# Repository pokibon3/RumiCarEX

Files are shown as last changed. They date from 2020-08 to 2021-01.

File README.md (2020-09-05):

# RumiCarEX
## Original RumiCar Project

### rumicar_esp32

- CPU        : ESP32 mini
- Chassis    : Original
- Steering   : Servo Motor 
- TOF Senser : VL53L1X
- Program    : Original

### rumicar_LiDAR(sense only)

- CPU        : M5Atom Matrix
- Chassis    : Original
- Steering   : Servo Motor 
- TOF Senser : LiDAR Camsense X1
- Program    : Original

### rumicar_atom

- CPU        : M5Atom Matrix
- Chassis    : Original
- Steering   : Servo Motor 
- TOF Senser : VL53L1X
- Program    : Original

### rumicar_xiao

 - CPU       : seeed xiao
 - Chassis   : DAISO 600 Yen Toy Radio Control Car
 - TOF Sensor: VL53L0X
 - Program   : RumiCar EX3.1

 ### libraries/LV53L1X

  - Add VL53L1X_SetROI function

### 1.Test
 
  - Test Programs

### 2.doc

  - related documents

### 3.Log

  - Driving Log

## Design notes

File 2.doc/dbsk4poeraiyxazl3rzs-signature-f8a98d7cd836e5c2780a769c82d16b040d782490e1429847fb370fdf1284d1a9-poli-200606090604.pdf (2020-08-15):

# RumiCarのモータ制御と今後の展開

### For 実機貸出有！【オンライン】RumiCarハンズオン！ 自動運転アルゴリズムを楽しく手軽に体感しよう！

ミイシステム株式会社） 稲玉 繁樹
Rev.)2020/06/06

いなたま しげき

ALL Pages Photo OK! | 四の人(IoT) @InatamaS

Mii system Co.,Ltd.

### RumiCar ライブラリによって，走らせる事は簡単になっていますが， - モータ制御って何？どうなってるの？ - 今後，どんな進化するの？ について説明します。

### 伝えたいこと

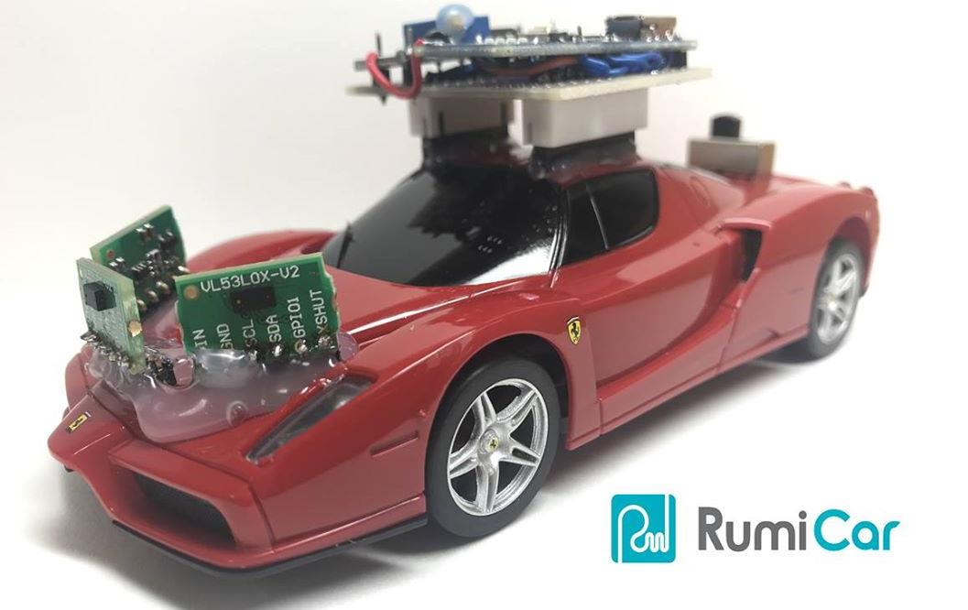
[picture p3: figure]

### - モータを動かすことは，とても楽しいです - 電気を扱うため，安全に注意してください - モータ制御は難しいけど理解するほど楽しいことができます，がんばろう - 正しい知識を持って，電子工作をもっと楽しもう

## Today’s contents

## Who

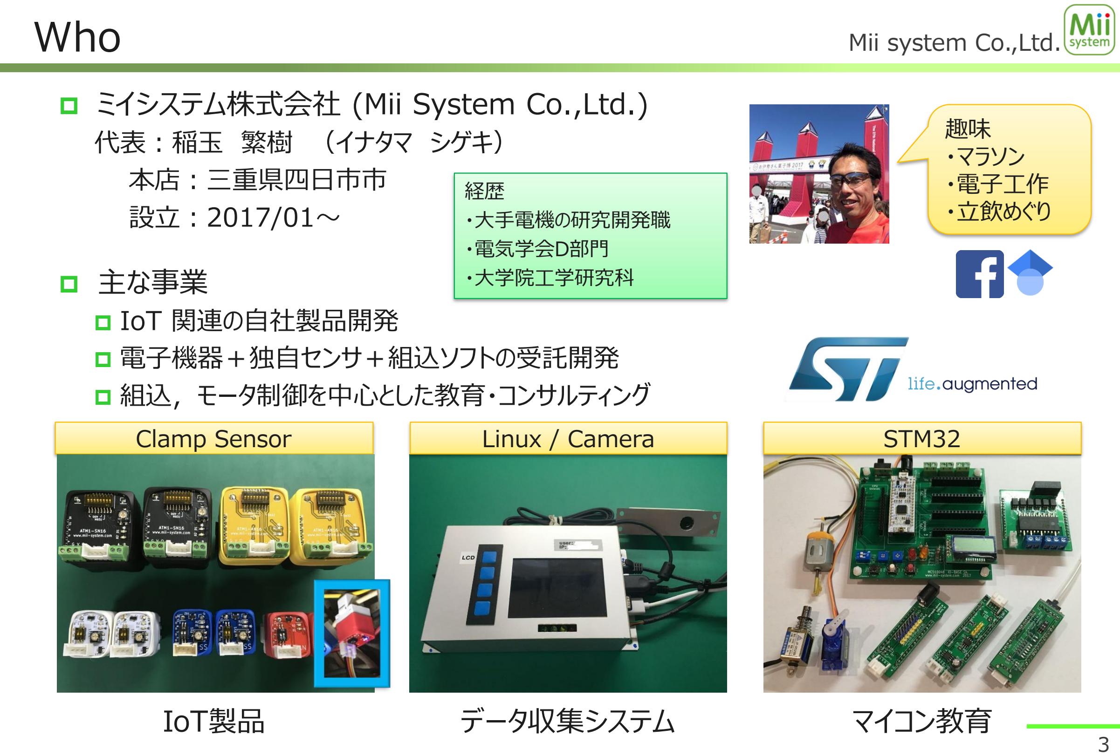
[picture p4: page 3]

Mii system Co.,Ltd.

マイコン教育

- ミイシステム株式会社 (Mii System Co.,Ltd.) 代表：稲玉 繁樹 （イナタマ シゲキ）
本店：三重県四日市市
設立：2017/01～
IoT製品 | データ収集システム
Clamp Sensor | Linux / Camera | STM32

趣味
・マラソン
・電子工作
・立飲めぐり
- 主な事業
- IoT 関連の自社製品開発
- 電子機器＋独自センサ＋組込ソフトの受託開発
- 組込，モータ制御を中心とした教育・コンサルティング

経歴
・大手電機の研究開発職
・電気学会D部門
・大学院工学研究科

## モータの種類

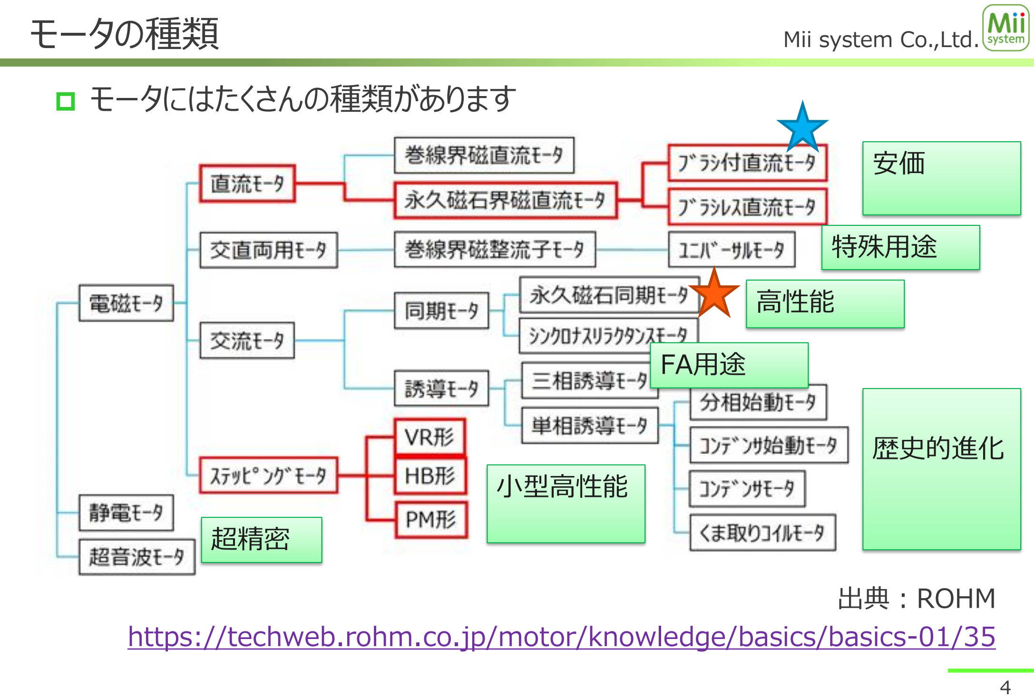
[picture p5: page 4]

Mii system Co.,Ltd.

### - モータにはたくさんの種類があります

出典：ROHM
https://techweb.rohm.co.jp/motor/knowledge/basics/basics-01/35

安価

小型高性能

超精密

特殊用途

高性能

FA用途

歴史的進化

Mii system Co.,Ltd.

### - DCモータ，about な理解 - 電池を入れると同じ方向に回り続ける - 電池の向きで回転する方向が変わる - 電池の本数で回転するスピードが変わる

### - DCモータが回転する仕組み

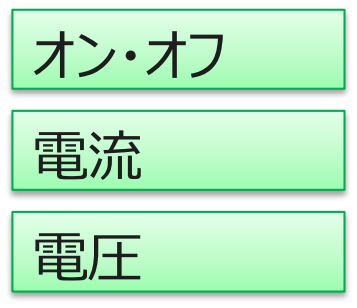
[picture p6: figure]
電流 電圧電圧

### マブチモーター株式会社-モーターのしくみを知ろう

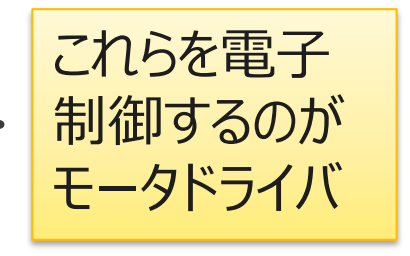
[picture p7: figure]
これらを電子 制御するのが モータドライバ

https://www.mabuchi-motor.co.jp/motorize/academy/mechanism/

## モータはなぜ回るのか

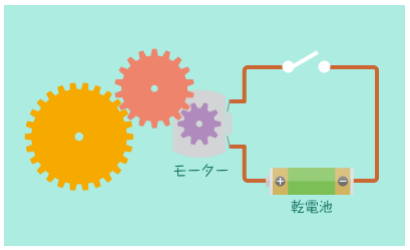
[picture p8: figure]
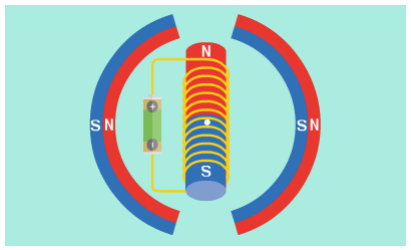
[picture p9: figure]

## モータ制御って何？

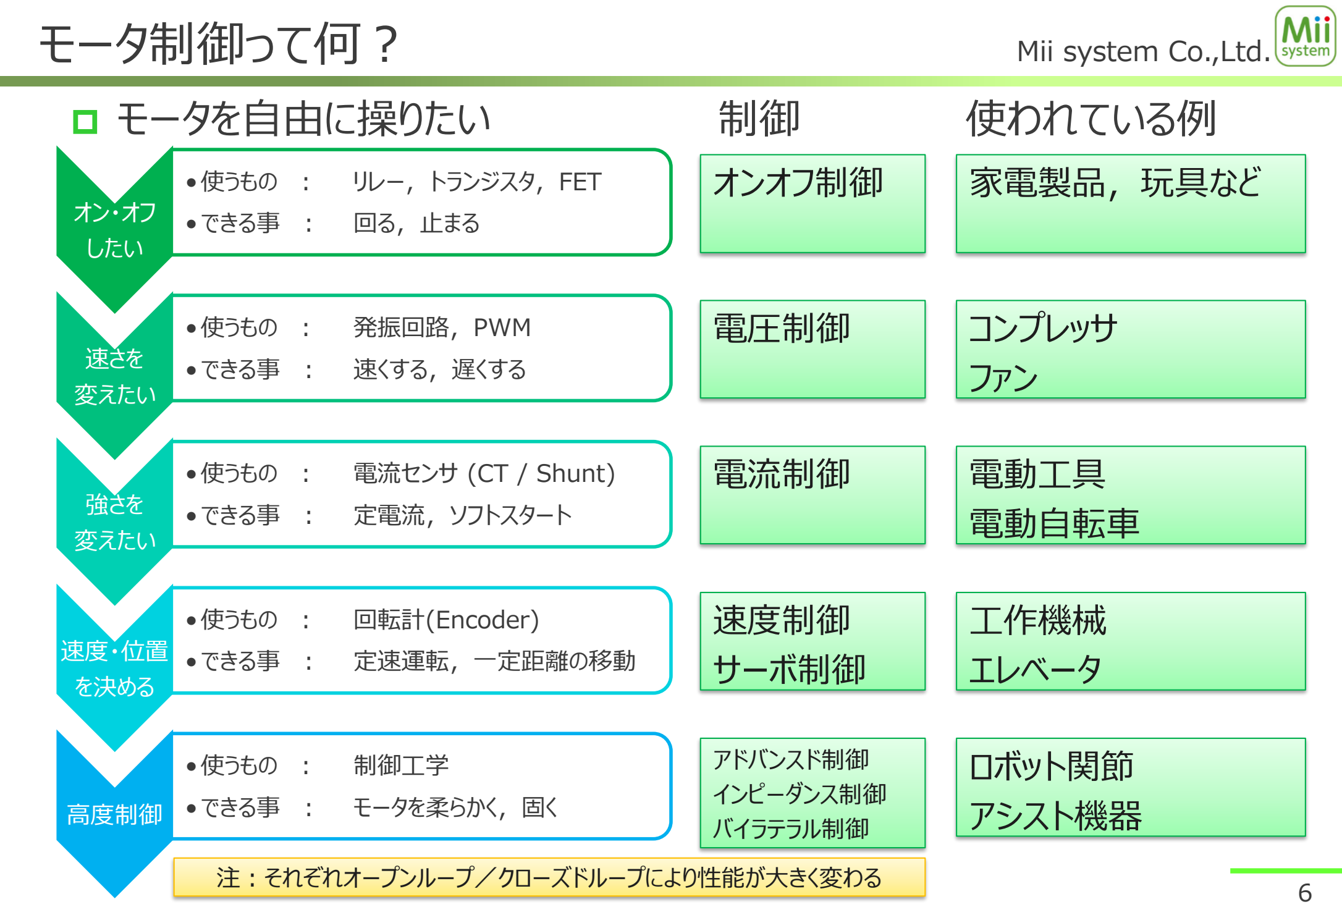
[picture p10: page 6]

Mii system Co.,Ltd.
- モータを自由に操りたい | 制御 | 使われている例

オン・オフ
したい
•使うもの ： | リレー，トランジスタ，FET
•できる事 ： | 回る，止まる

速さを
変えたい
•使うもの ： | 発振回路，PWM
•できる事 ： | 速くする，遅くする

強さを
変えたい
•使うもの ： | 電流センサ (CT / Shunt)
•できる事 ： | 定電流，ソフトスタート

速度・位置
を決める
•使うもの ： | 回転計(Encoder)
•できる事 ： | 定速運転，一定距離の移動

高度制御

•使うもの ： | 制御工学
•できる事 ： | モータを柔らかく，固く

家電製品，玩具など

コンプレッサ
ファン

電動工具
電動自転車

工作機械
エレベータ

ロボット関節
アシスト機器

オンオフ制御

電圧制御

電流制御

速度制御
サーボ制御

アドバンスド制御
インピーダンス制御
バイラテラル制御

注：それぞれオープンループ／クローズドループにより性能が大きく変わる

Mii system Co.,Ltd.

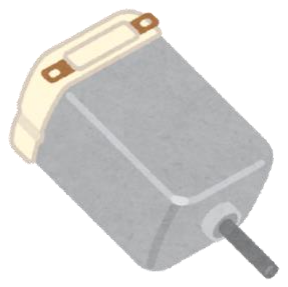
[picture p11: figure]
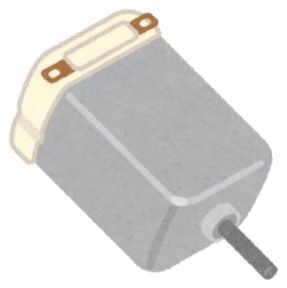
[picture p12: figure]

### - 走る・曲がる・止まる の性能アップ

- 一定速度で走る，なめらかな加減速
- ステアリング用エンコーダで切れ角を制御

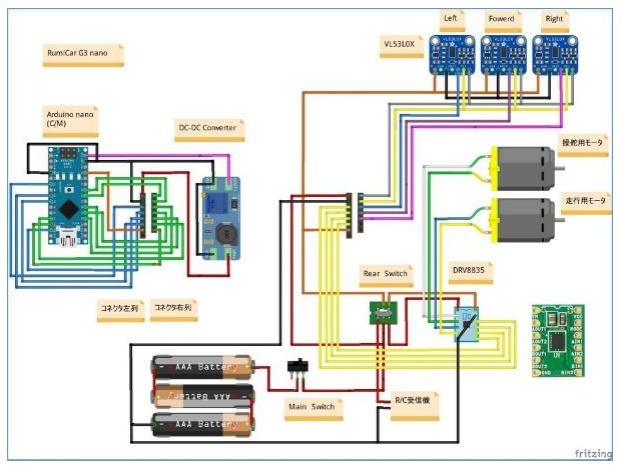
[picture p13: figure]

### - ユニット化で組み立てやすく

- センサ基板 / CPU基板 / MD基板を標準化
- はんだ付けを減らし，組立しやすく

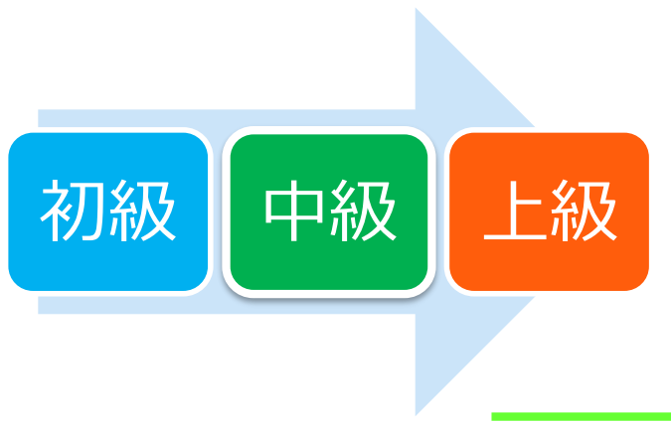
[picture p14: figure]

### - ソフトを作りやすく / 高度化へ

- Node-red / UIFlow などのブロック言語を活用
- ESP32 のWi-Fi (OTA) 書き込み
- Wi-FiでMD/センサ情報をやりとりし，PC側で制御する

## RumiCar 新バージョンの構想

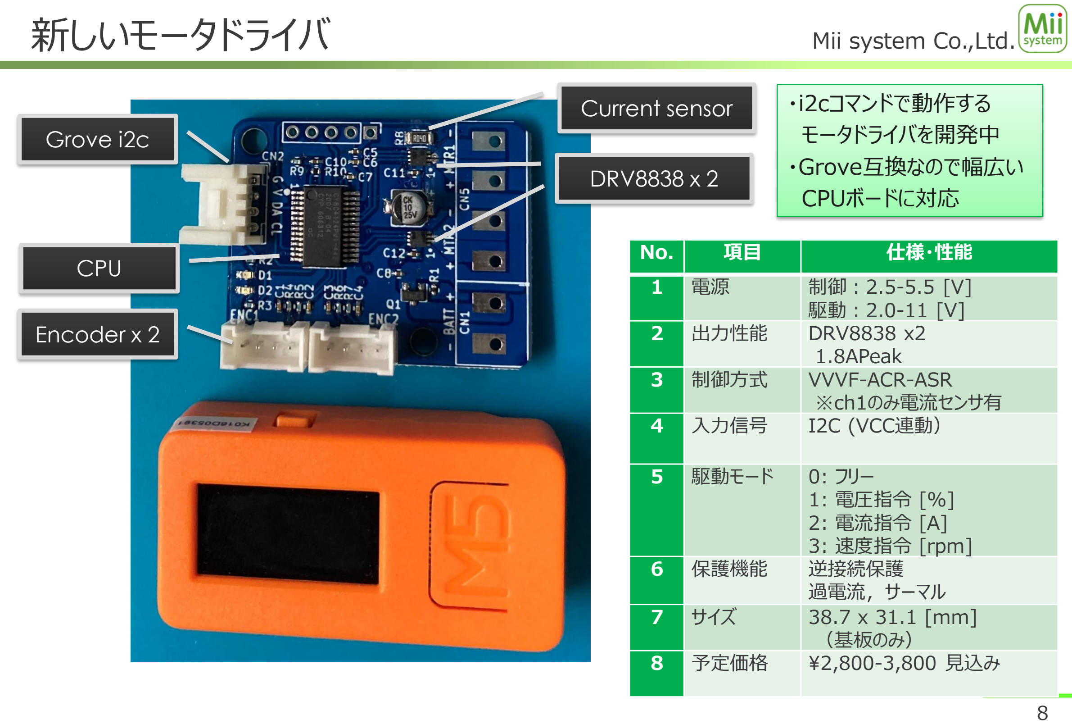
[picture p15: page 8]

新しいモータドライバ | Mii system Co.,Ltd.

Grove i2c

Encoder x 2

Current sensor

DRV8838 x 2

CPU

No. | 項目 | 仕様・性能
1 | 電源 | 制御：2.5-5.5 [V] 駆動：2.0-11 [V]
2 | 出力性能 | DRV8838 x2 1.8APeak
3 | 制御方式 | VVVF-ACR-ASR ※ch1のみ電流センサ有
4 | 入力信号 | I2C (VCC連動）
5 | 駆動モード | 0: フリー 1: 電圧指令 [%] 2: 電流指令 [A] 3: 速度指令 [rpm]
6 | 保護機能 | 逆接続保護 過電流，サーマル
7 | サイズ | 38.7 x 31.1 [mm] （基板のみ）
8 | 予定価格 | ¥2,800-3,800 見込み

・i2cコマンドで動作する
モータドライバを開発中
・Grove互換なので幅広い
CPUボードに対応

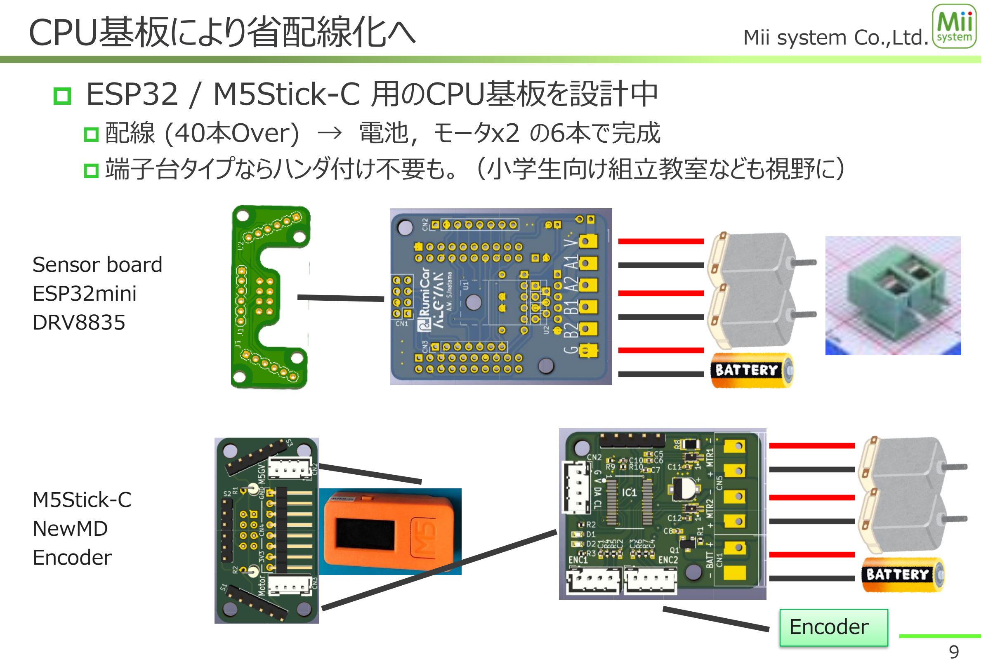
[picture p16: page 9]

CPU基板により省配線化へ | Mii system Co.,Ltd.

### - ESP32 / M5Stick-C 用のCPU基板を設計中

- 配線 (40本Over) → 電池，モータx2 の6本で完成
- 端子台タイプならハンダ付け不要も。（小学生向け組立教室なども視野に）

Sensor board
ESP32mini
DRV8835

M5Stick-C
NewMD
Encoder

Encoder

ソフトを作りやすく・高度化のために | Mii system Co.,Ltd.

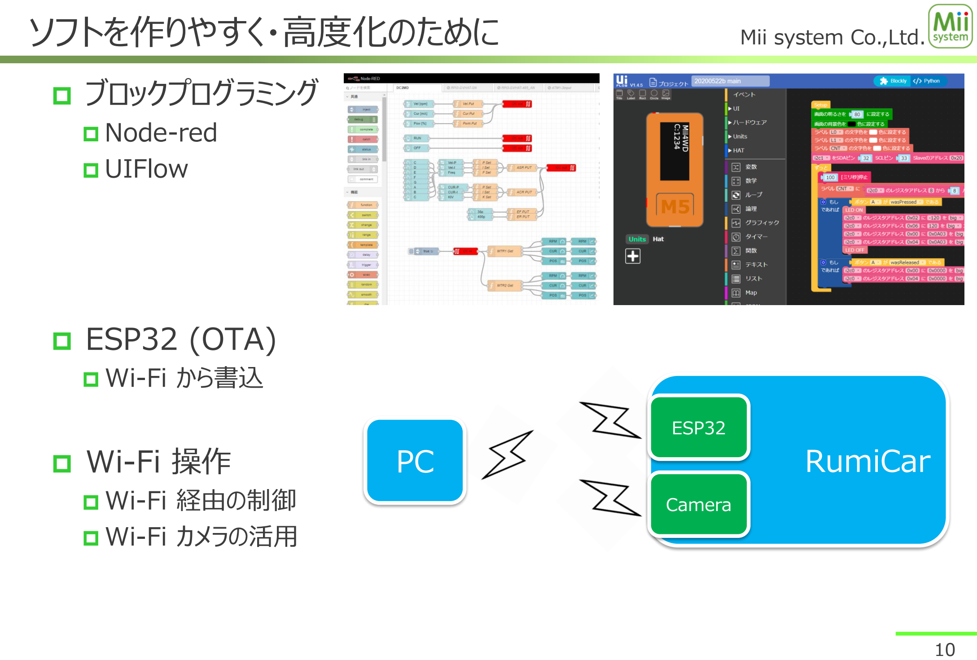
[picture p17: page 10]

### - ブロックプログラミング

- Node-red
- UIFlow

### - ESP32 (OTA)

- Wi-Fi から書込

### - Wi-Fi 操作

- Wi-Fi 経由の制御
- Wi-Fi カメラの活用
PC | RumiCar

ESP32

Camera

Mii system Co.,Ltd.

### - モータ制御の改善で RumiCar がパワーアップできます！ - 組立を簡単にして，参加しやすい環境を作ろう！ - CPU / SOFT 対応を広げて，凄い運転を作ろう！

## まとめ

www.mii-system.com
inatama-shigeki@mii-system.com

### ご清聴ありがとうございました！

Sildeshare します。

いなたま しげき

### 代表：稲玉 繁樹

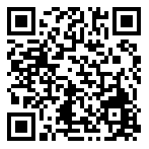
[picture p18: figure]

四の人(IoT) @InatamaS

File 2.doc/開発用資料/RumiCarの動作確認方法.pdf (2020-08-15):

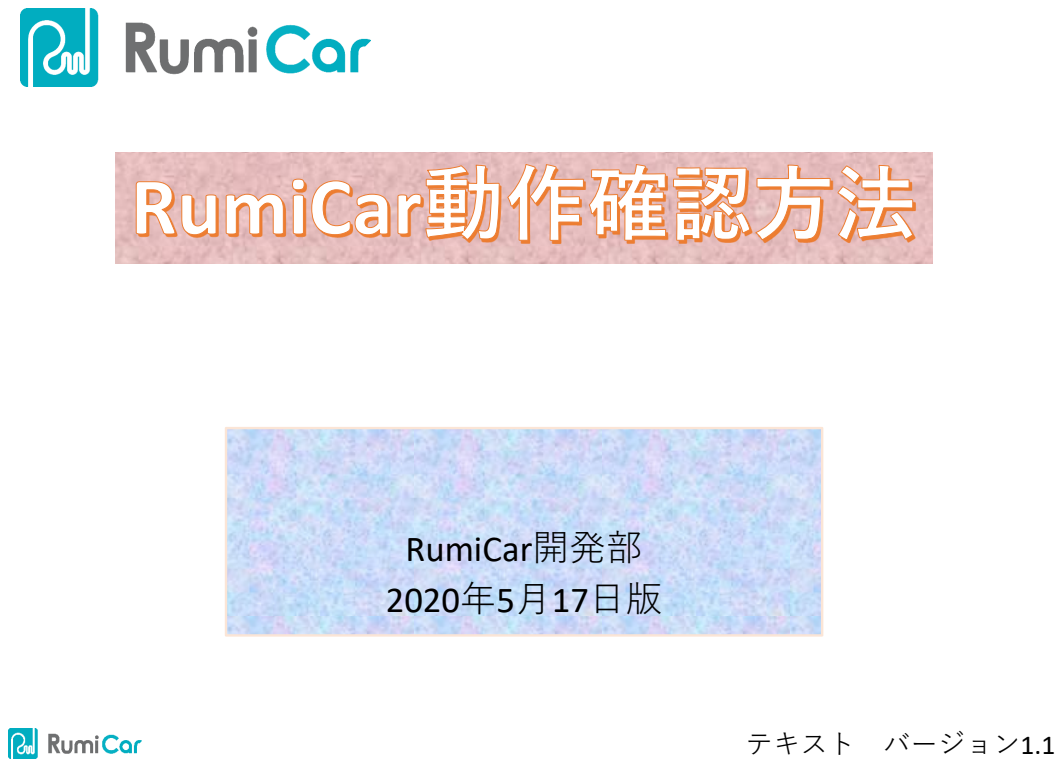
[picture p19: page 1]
RumiCar開発部 2020年5月17日版; テキスト バージョン1.1

概要

- この資料はRumiCarとコンピュータモジュール(以 下CMと記す)の各部の接続が正常かどうか確認す
るものです
- まず、3基のVL53L0X測距モジュールの測距データ を表示させ確認することにより測距モジュールの 接続が正常であることを確認します
- 次にハンドルと後輪を動作させてモータ関係の接 続が正常であることを確認します
- これらの動作が想定どおりでない場合は、はんだ 付けが間違っている、ちゃんとくついていない、 接触不良など、どこかに不具合がありますので接 続を確認して修理や修正します。
製作・著作：RumiCar開発部 | 2

準備

注意点、必要なもの、準備

# ケーブルの抜き差し注意点

- まずCMにUSBケーブルを接続する
- それからCMを車体に接続する
- 注意！車体にCMを装着した状態でCMにUSB
ケーブルを接続しないこと
- 車体にCMを装着したままUSBケーブルを抜か
ないこと
- CMコネクタ部分に過度な力が加わり破損の原
因になります

# ケーブルの抜き差し注意点

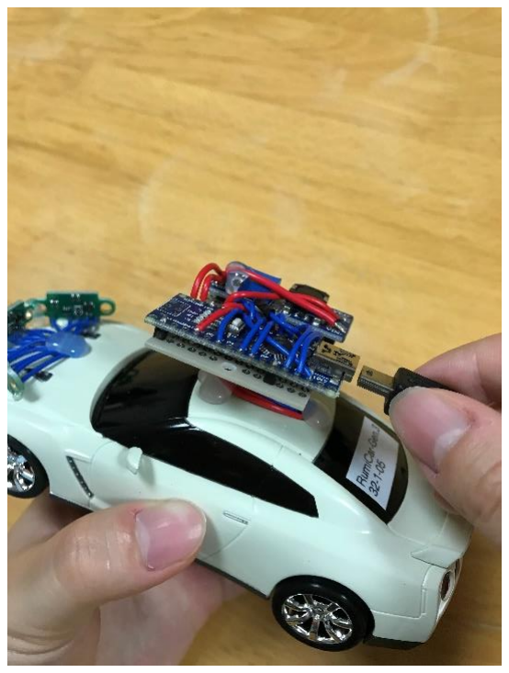
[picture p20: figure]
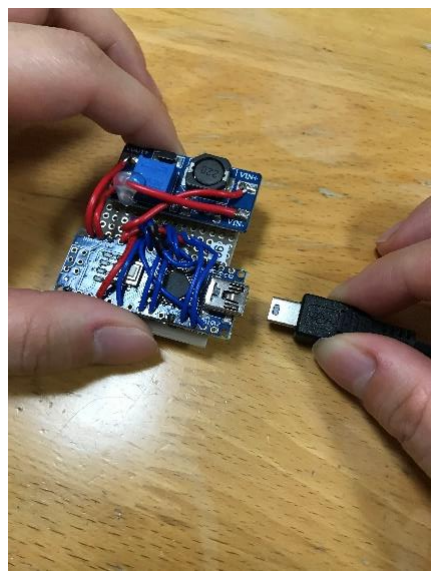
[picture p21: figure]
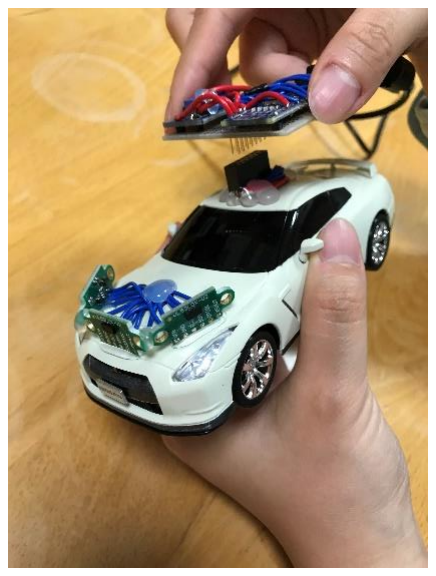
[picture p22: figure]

CMをRumiCar車体につけたままUSBケーブルの抜き差しを しない！

# コンピュータ制御へ設定

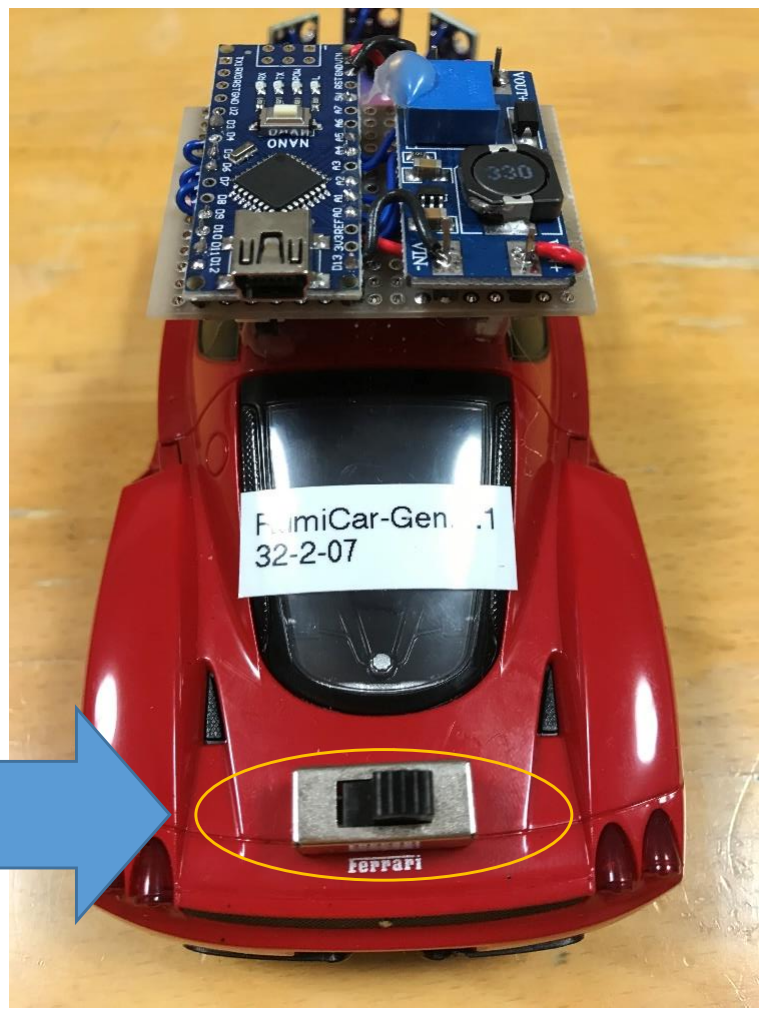
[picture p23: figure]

- （一部のモデルのみ）
- マニュアル制御とコンピュータ制御の切
り替えスイッチ好きモデルは切り替えス
イッチを右側へ切り替えます
- 右側がコンピュータ制御側です
- 右側にするとCM（ArduinoやESP32）から の命令で走ります
- （左側にするとラジコンで操作できるよ
うになります）

# 必要なもの

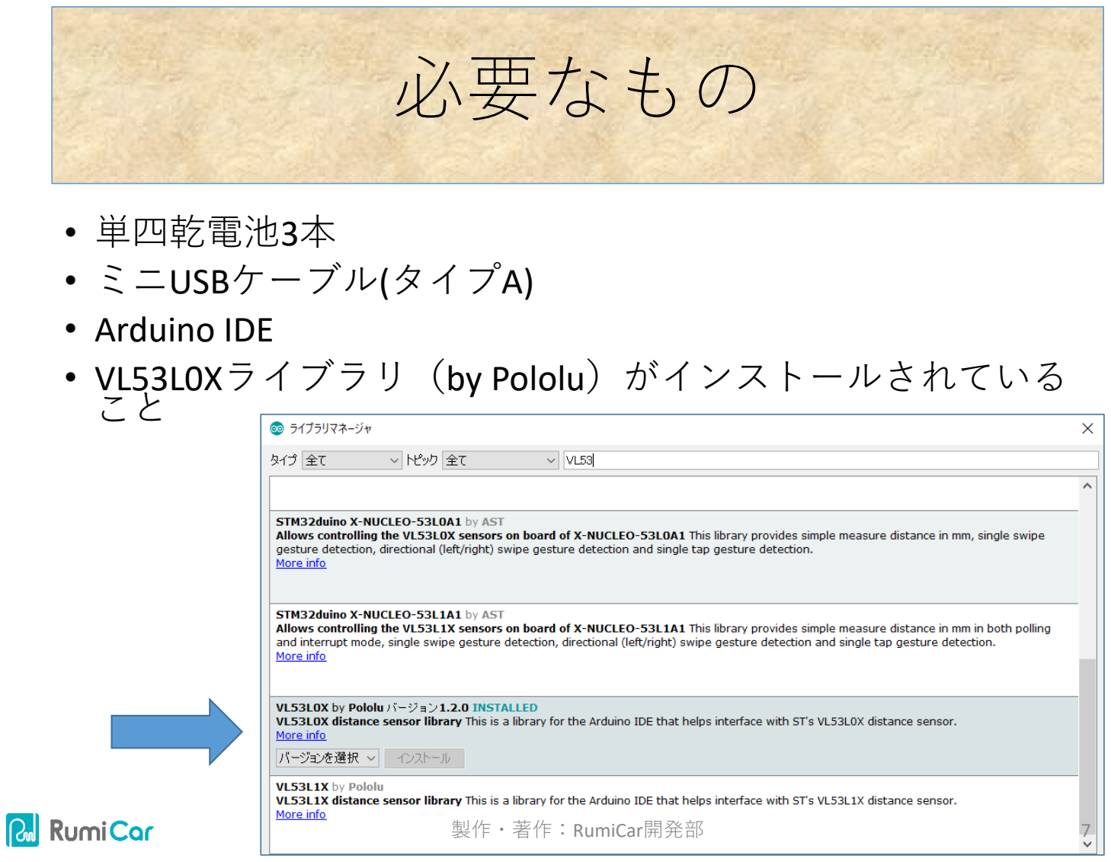
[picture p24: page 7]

- 単四乾電池3本
- ミニUSBケーブル(タイプA)
- Arduino IDE
- VL53L0Xライブラリ（by Pololu）がインストールされている こと

# デバイスとCOMポートの確認

- RumiCarのコンピュータモジュールの標準のデバ イスはCH340と表示されますが、自作やその他の
Arduino場合は別なデバイス名になる可能性があり ますのでその時は注意してデバイスを探してくだ
さい
- 以降も同様ですので必要に応じてご自分のデバイ
ス名に読み替えて作業してください

# COMポートの確認 （Windowsの場合）

- RumiCarのCMをUSBケーブルでパソコンに接続す る
- デバイスマネージャで接続されたCOMポート番号
を確認する。CH340を探します（番号を覚えてお
くこと）

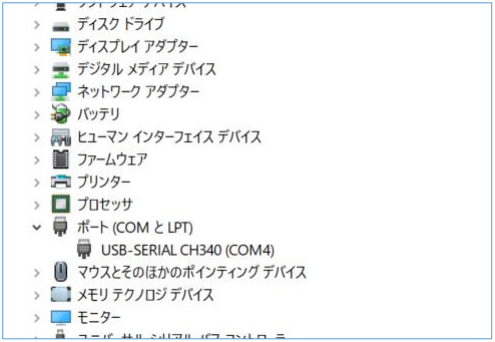
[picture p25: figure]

Arduino nanoの
モデルにより
デバイスの表
示が異なる場
合があります

# COMポートの確認 （Macの場合）

- Terminalソフトを起動します
- コマンド”ls –l /dev/tty.usb”と入力することで接続 されているCOMポートの一覧を表示させることが
できます
- Arduinoが接続されたCOMポート番号を確認する CH340を探します（番号を覚えておくこと）

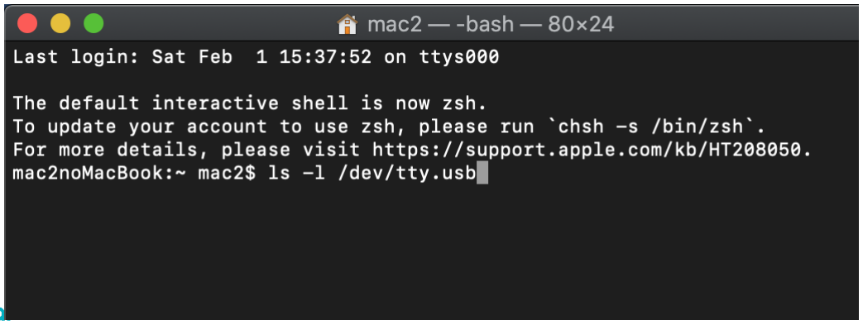
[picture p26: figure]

# Arduino IDEの設定

- ボード：Arduino Nano
- プロセサ：ATmega328P(Old Bootloader)
- シリアルポート：デバイスマネージャで確認した番号

RumiCar CM デフォルト


# Arduino IDEの設定

- ボード：Arduino Nano
- プロセサ：ATmega328P(Old Bootloader)
- 自作の場合はご自分で用意したArduino Nanoタイプに 合わせます

RumiCar CM デフォルト


# 接続確認用プログラムの準備

- GitHub
- https://github.com/algyan/RumiCar/tree/master/ArduinoAndESP32/Samples
- ファイル名


# 接続確認用プログラムの準備

- GitHubよりPullすると3つのファイルがダウンロードさ れます
- そのうち、下記のプログラムをArduino IDEで開きます


## プログラムの実行 距離の測定確認

- 距離の測定確認フロー
1. RumiCarの電源をオフにします(最後までオンにし ません)
2. CMをRumiCar車体から取り外します
3. CMにUSBケーブルを取り付けます
4. USBケーブルをパソコンに接続します
5. CMをRumiCar車体に取り付けます
6. シリアルモニタを立ち上げます
7. コンパイルしプログラムをCMに書き込みます
8. シリアルモニタに3基のVL53L0X測距モジュールの 測距値が表示されます

# VL53L0Xの接続の確認

- 測定値を表示させるためにシリアルモニタを開きま
す
- ツール -> シリアルモニタ


## コンパイルと書き込み

- コンパイルとボードへの書き込み


押す

# VL53L0Xの接続の確認

- 下記のように距離が表示されれば正常です。セン サーの前で手を動かすなどしたら、表示される距 離が変化しますか？
- センサーは、左がSensor0、中央がSensor1、右が Sensor2です


## プログラムの実行 モーターの動作確認

- モータの動作確認フロー
1. (距離の測定をしたままの状態から継続で良いで
す)
2. CMをRumiCar車体から取り外します
3. CMからUSBケーブルを取り外します
4. CMをRumICar車体に取り付けます
5. RumiCarを手に持ったままRumiCarの電源をオンに します
6. ハンドルが、まず右に曲がり、次に左に曲がって、 最後に中央に戻ります
7. 後輪が、まず前進方向に回転し、次に後進方向に
回転して、最後に停止します
8. ハンドルと後輪が上記の順序に動作すれば正常で
す | 製作・著作：RumiCar開発部 | 19

# 確認事項詳細

項目 | 症状 | 考えられる可能性 | 主要確認・対応項目
| CMが再起動を繰り返すのみでプログラム自 体が実行されない | VL53L0X関係の結線に不具合 がある可能性があります | ①XSHUT ②7番ピン
| センサーの前で手を動かしても測距値が変 わらない | | ①当該センサー ②I2C(SCL、SDA)
| センサーの測距値が8190前後の値しか表示 されない | 8190はレーザーの反射を捉 えられていない状況を示し ます
| センサーの値の変化が下記に合っていない Sensor0:左 Sensor1:中 Sensor2:右 | 動作しているものの接続先 が誤っている可能性があり ます | XSHUT
モーター関係 | 左、右、前進、後進、のうち、動かないも のがある | 一部の接続不良の可能性が あります | 操舵の場合はAINxからAOUTx、 走行系の場合はBINxから BOUTxを調べる 例えば前進はBIN1からBOUT1 までの接続になります
| 動作順序が下記になっていない ①ハンドル右 ②ハンドル左 ③前進 ④後進 | 動作はしているものの接続 先が誤っている可能性があ ります

センサー関係

接続を調べる場合はCM内CPU(例えばArduino)のピンからソケットを経てセンサーやモータドライ バ、モータ迄の当該経路を全部調べた方が良いでしょう

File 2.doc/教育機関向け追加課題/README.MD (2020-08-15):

RumiCarを教材として教育機関にて授業や演習で利用する場合の追加課題です
Rumicarハンズオンの資料にはRumiCarの仕組みや構成を学べるように作られています
学生が自ら更に深く考えて課題を克服しより良いアルゴリズムを開発できるように研究課題の基礎やグループワークに使えるように追加の課題をまとめました
是非ご利用ください

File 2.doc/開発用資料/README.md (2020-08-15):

# RumIcarを自作する場合の資料とRumiCarの動作確認用の資料です
1.RumiCarを自作する場合はまず「RumiCarの作り方」をご覧頂きRumiCarを作成後、作成したコンピュータモジュールとRumiCarが正しく作成できているかの確認のために
「RumiCarの動作確認方法」の内容に従ってご確認ください
是非多くの人たちにオリジナルのRumiCarを作成頂きRumiCarの世界を楽しんで頂けると嬉しいです
1.1コンピュータモジュールの作製においてArduino Nano以外のコンピュータモジュール作成のための情報を追加しました
1.2ステアリングをサーボ化する場合のピンアサイン(13番ピン)を追加しました

2.RumiCarを受け取ったり運送等により故障していないかを確認する場合は「RumiCarの動作確認方法」の内容に従ってRumiCarが正常動作するかご確認ください

3.各コンピュータモジュール別のピンアサイン表があります。プログラムの互換性確保のためコンピュータモジュールを自作する場合の結線はそれに従ってください

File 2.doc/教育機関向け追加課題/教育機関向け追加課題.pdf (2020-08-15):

RumiCar開発部 2020年5月20日版; テキスト バージョン1.0

概要

- この資料はRumiCarを教育機関において教材と して使用する場合の追加資料です
- RumiCarハンズオン資料等ではRmiCarの基本構 造や仕組み、測距、得られた情報に従っての車
両制御の基礎を学ぶことができます
- 本資料では、生徒が自ら考えることにより課題
の克服や、より良いロジックを発想することを
目的として追加課題としてまとめてあります
製作・著作：RumiCar開発部 | 2

課題１

スタックの回避

## 課題１：スタックの回避

- 下記の動画を視聴してください。RumiCarの試 走風景です
- https://www.youtube.com/watch?v=LUMCizYnTlw&list=PLizQwd7qivbjCSXyGGtFbZfkKpPRBjdZD&index=15

## 課題１：スタックの回避

- １部の車両がスタック(立ち往生)しています


注目

## 課題１：スタックの回避


- 動画のプログラムはハ
ンズオン3.2です。主要
部分を左に示します
- 課題1-1
- なぜスタック挙動になっ
ているか説明しなさい
- 課題1-2
- スタックしないようにフ
ローを作成しプログラミ
ングしなさい

課題２

追い越し

## 課題２：追い越し

- 下記の動画を視聴してください。RumiCarの試 走風景です
- https://www.youtube.com/watch?v=4Xmve4TRM10&list=PLizQwd7qivbjCSXyGGtFbZfkKpPRBjdZD&index=16

## 課題２：追い越し

- 動画のプログラムはハ
ンズオン3.1です。主要
部分を左に示します。
このプログラムでは前
走車に追いつくと停止
または後進するように
なっています
- 課題2
- 追い越しをするフローを
考えプログラミングしな
さい


課題３

交差点

## 課題３：交差

- 課題3
- ８の字のコースを想定し交差点を安全に通過するフ
ローを考えてプログラミングしなさい
- 道路幅は30cm、車体幅は10cmとします
- 交差点は直交
- 交差点進入時に左右からの侵入車を検知した場合は当該 車両が通過し自車が通過可能になったら通過する
- 左右からの侵入車は複数台連続していることを想定する こと
- 既に交差点で通過待ち停車中の先行車がある場合はその 先行車後方で停車すること

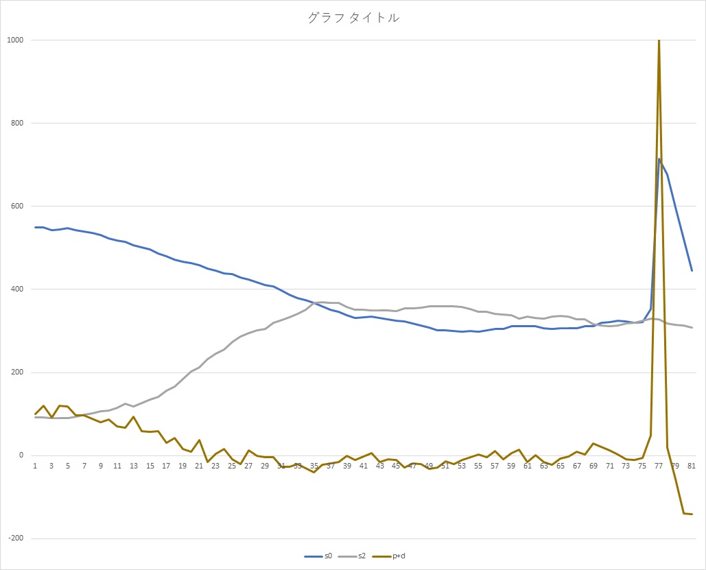
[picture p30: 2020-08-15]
3.Log/pid.jpg

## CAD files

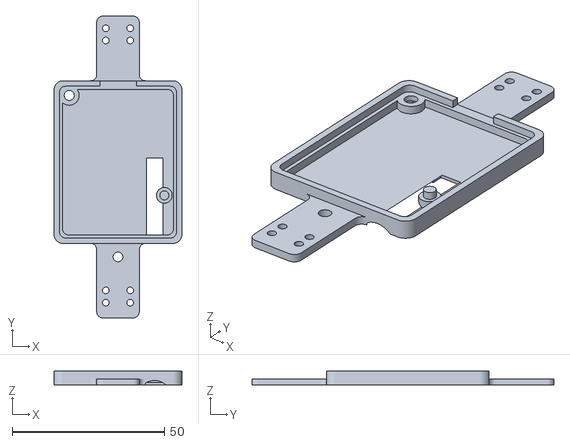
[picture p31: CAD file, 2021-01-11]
4.STL/K989/K989_CPU_BASE8.stl
42.0 x 99.0 x 4.60

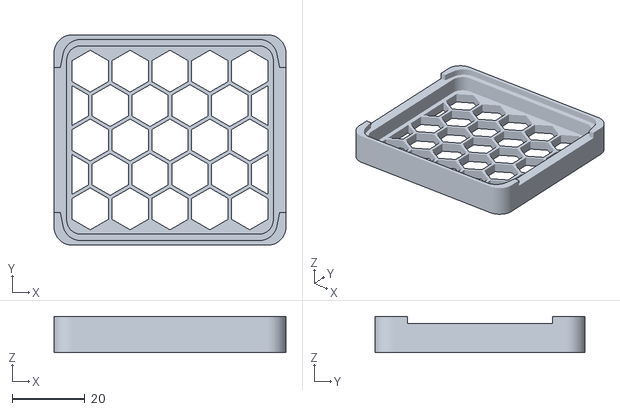
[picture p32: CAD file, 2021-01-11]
4.STL/K989/base_stand3.stl
64.0 x 58.0 x 10.0

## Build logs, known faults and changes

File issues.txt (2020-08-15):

#issues 2020/06/20

1. １号車
(1) 仕様
　(a) ソフト：rumicar_xiao_v1.ino
    アルゴリズムはExercise-3.2準拠
　(b) シャーシ：ダイソー600円トイラジコン
　(c) CPU：Seeed XIAO
　(d) 測距センサ：VL53L0X
(2) 成果
    オーバルコース  ： 〇
    ジグザクコース  ： △
    ８の字コース    ： ×
(3) 問題点
　(a) スピードがオリジナルに比較して早い
　(b) 前を走る標準RumiCarに衝突する
    フロントのセンサーが高い影響？
　(c) 左に曲がらないことがある
    電池の消耗の影響
    モーターの左右トルクの差の影響？
　(d) 八の字コースの交差部分を直進しない
    標準アルゴリズムでは対応困難
　(e) ステアリングの切れ角小
    サーボ版(rumicar_atom_V6)以降で対策
(4) 評価
　シンプルなソフトの潔いステアリングコントロール
　が実際のコースでは非常に有効。

2. ２号車
(1) 仕様
　(a) ソフト：rumicar_atom_v91.ino
            ① BLYNK　BLEリモコンサポート
            ② 測距センサをVL53L1Xに変更
            ③ 衝突時の切返しモード追加
            ④ モーター制御のタイマータスク化
            ⑤ アウトインアウト風制御追加
            6 交差点対策
　(b) シャーシ：servo steeringオリジナルシャーシ
　(c) CPU：M5Atom Matrix
　(d) 測距センサ：VL53L0X
(2) 成果
    オーバルコース  ： ×
    ジグザクコース  ： ×
    ８の字コース    ： ×
(3) 問題点
　(a) スピードがオリジナルに比較して早い
    モーターのスピード制御がダメ
    低速トルク不足で、衝突時に脱出できない
　(b) コーナーが不安定（蛇行し壁に衝突）
    ① センサー位置が低いため、床、壁の測距性能低
    　6/20のコースの長机では測距範囲は約40cm
    　自宅コースでは、100cm以上の測距が可能
    　床の影響大
    ② トイラジコンのDCモータによるステアリング制御
    　に比較して、減速ギアのあるサーボはレスポンスが
    　遅いため、制御に遅れが発生し振動が収束しない
    　(a)の影響もある
　(c) ステア時に曲がりすぎる
    ステアリング制御がシビア
    本来はpid制御が必要？でも簡単にやってみたい！
　(d) アウトインアウトアルゴリズム不発
　　一定時間のコーナリングが継続したら、イン側に
    コースを変える制御に入らない
　　(a)の影響
　(e) 8の字対策不発
　　フロントセンサーが80cm以上を測距したら舵角を
　　絞る制御に入らない
　　(a)のフロントセンサー影響
　(f) 切返しモードが一発できまらず、逆行することがある
    後退時の制御（パラメータ）検討不足
(4) 評価
　基本性能が作りこみ不足で、追加対策が不発
　熟成不足

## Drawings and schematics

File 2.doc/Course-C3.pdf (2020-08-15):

1 8 0 0

1 3 5 0

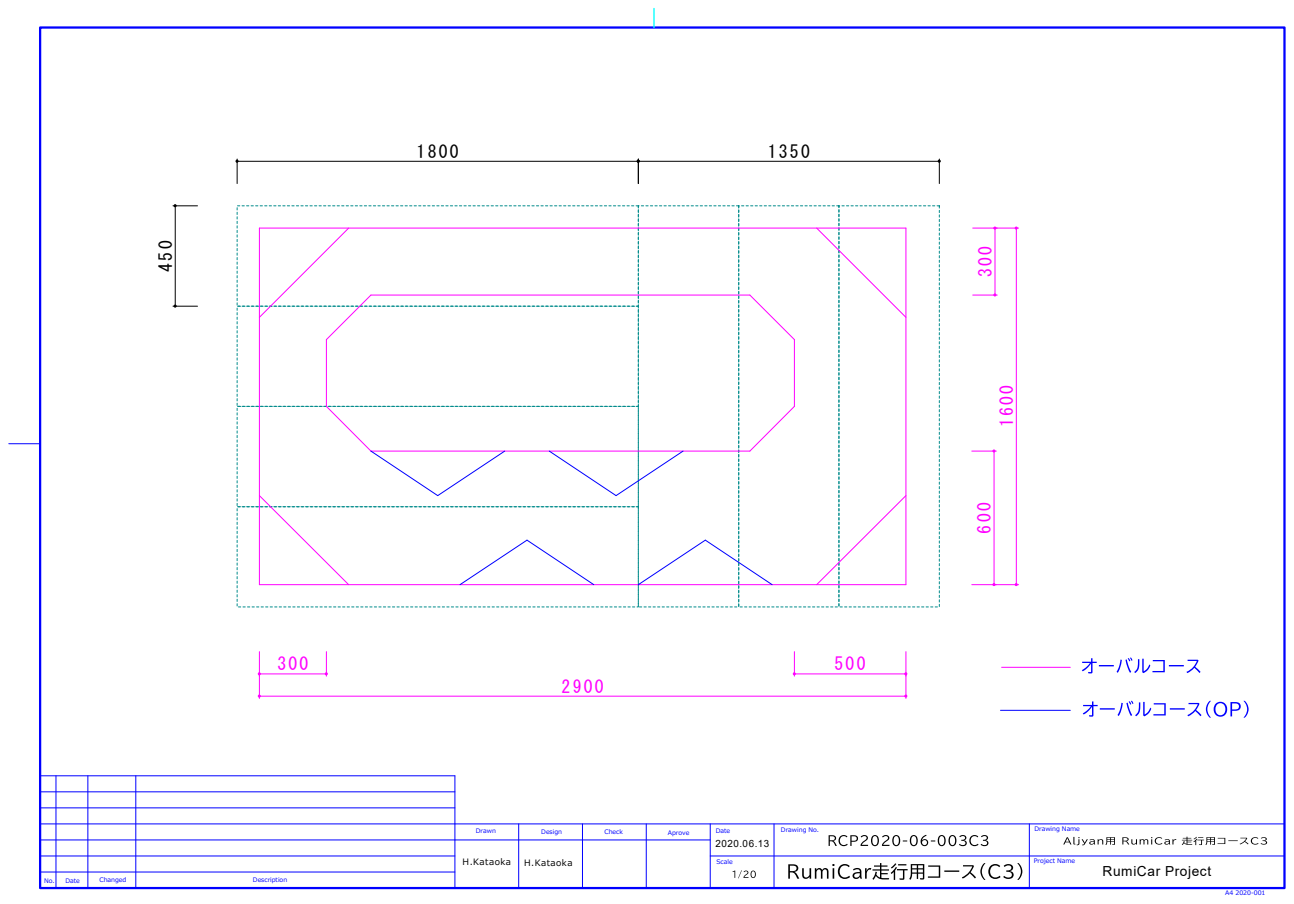
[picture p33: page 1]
Scale Date; Drawing No.; Drawing Name Project Name Drawn; Design; Check; Aprove No.; Date; Changed; Description; A4 2020-001 H.Kataoka; H.Kataoka; RumiCar Project

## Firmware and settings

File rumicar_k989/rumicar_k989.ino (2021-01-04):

//=========================================================
//  rumicar_esp32.ino :  RumiCar application
//  History     : V1.0  2020-08-18 new create
//                V2.0  2020-12-04 Support K989
//                V2.1  2020-12-13 Add Battery Check
//                V2.2  2020-12-15 Add Semi AutoDrive
//=========================================================
#include <Wire.h>
#define  EXTERN extern
#include "RumiCar_esp32.h"
#include "BluetoothSerial.h"
#include "driver/adc.h" 
#include "esp_adc_cal.h"

#define BT_ON
#ifdef BT_ON
BluetoothSerial SerialBT;
#endif
//=========================================================
//  RumiCar Default Parameter
//=========================================================
#define DEVICE_NAME     "RumiCar_K989" // BLE Device Name
#define PILOT_MODE      1         // 1:Auto 2:Manual
#define MAX_TORQUE      255       // max pwm value
#define MAX_POWER       200       // 230 max              K989:200
#define MIN_POWER       150       // 120 min
#define MAX_SPEED       1.0       // max speed factor
#define MID_SPEED       0.75      // mid speed factor
#define LOW_SPEED       0.5       // low speed need torque
#define BRAKE_TIME      1000      // coasting max time
#define MAX_DISTANCE_W  300       // max distance to wall
#define MID_DISTANCE_W  150       // keep distance from inside wall
#define MIN_DISTANCE_W  0         // min distance to wall
#define MAX_ANGLE       100       // max 100%
#define KIRIKAESHI_ANGLE 95       // kirikaeshi reverse angle
#define LIMIT_ANGLE      30       // max  30%
#define OVR_DISTANCE_F  500       // 800mm  detect straight  500:K989
#define MAX_DISTANCE_F  300       // 300mm  detect front wall
#define MID_DISTANCE_F  200       // 200mm  speed down distance
#define MIN_DISTANCE_F  100       // 100mm  reverse start distance
#define REVERSE_DISTANCE 150      // 100mm  reverse distance
#define STP_DISTANCE_F  0         // 0mm kiss to wall
#define REVERSE_TIME    200       // reverse time 500ms
#define OIO_OFFSET      50        // out in out offset 0=off
#define OIO_TIME        500       // continue 500ms to inside
#define MAX_STOP_TIME   4         // stop time(for reverse mode)
#define KP_CONST        1.0       // Konstante p
#define KD_CONST        0.1       // Konstante d
#define DMODE           0         // Differential control mode
                                  // 1: normalize 0:active
#ifdef  SENSOR_VL53L1X            // use VL53L1X
VL53L1X sensor0;                  // create right sensor instanse
VL53L1X sensor1;                  // create front sensor instance
VL53L1X sensor2;                  // create left  sensor instance
#else                             // use VL53L0X
VL53L0X sensor0;                  // create right sensor instance
VL53L0X sensor1;                  // create front sensor instance
VL53L0X sensor2;                  // create left  sensor instance
#endif

#define BODY_CLEARANCE_F  40      // offset of front sensor
#define BODY_CLEARANCE_W  30      // offset of side sensor

esp_adc_cal_characteristics_t adcChar;
//=========================================================
//  auto pilot variables difinition
//=========================================================
static int s0, s1, s2;                   // left, center, right sensor value
static int rawS0, rawS1, rawS2;          // sensor row value
static int ps0 = 0, ps1 = 0, ps2 = 0;    // left, center, right pre sensor value
static int st0, st1, st2;                // left, center, right sensor status
static int curDriveDir = BRAKE;          // current direction
static int lastDriveDir = BRAKE;         // last drive direction
static int lastSteerDir = CENTER;        // last steer direction

static unsigned long steerCount[3];      // steer count
static int courseLayout = 1;             // 0:LEFT 2:RIHGT 1:unknown
static float prep = 0;                   // pre value of proportional control
static float p;                          // proportional control
static float d  = 0;                     // differential control
static float d1 = 0;
static float d2 = 0;
static float kp = KP_CONST;
static float kd = KD_CONST;
static unsigned long preTime = 0;
static unsigned long dTime = 0;
static int dMode = DMODE;                // difference control mode
static int16_t Joy_X = 0;                // JoyStick X
static int16_t Joy_Y = 0;                // JoyStick Y
static int16_t autoPilot = PILOT_MODE;   // Default Pilot Mode
static int16_t Trim = 0;                 // Default Trimmer value
static int16_t maxSpeed  = MAX_POWER;    // Default Max Motor Power
static unsigned long sFwdTime = 0;       // fwd passage time
static unsigned long eFwdTime = 0;       // fwd passage time
static unsigned long sCornerTime = 0;    // cornering passage time
static unsigned long eCornerTime = 0;    // cornering passage time
static int preDistance    = 0;           // previous distance(S1)
static int preSpeed       = 0;           // previous speed
static int targetSpeed    = 0;           // target speed
static int requestTorque  = 0;           // PWM Value
static int curSpeed       = 0;           // current speed
static int reverseMode    = 0;           // reversing
static int stopCounter    = 0;           // stop times
static int steerDir;                     // steering direction
static int dAngle;                       // steering angle
static int oioCount       = 0;           // oio count
static int cornerFlag     = 0;           // oio mode flag
static uint32_t voltage   = 0;           // Battery voltage
static uint32_t pVoltage  = 7200;        // Battery previous voltage
static int BatCheckCount  = 0;
//=========================================================
//  Arduino setup function
//=========================================================
void setup()
{
  int i;
  for (i = 0; i < 3; i++) {
    steerCount[i] = 0;
  }
  RC_setup();               //   RumiCar initial function
#ifdef BT_ON
  Serial.println("Start bluetooth!");
  SerialBT.begin(DEVICE_NAME);
  Serial.println("The device started, now you can pair it with bluetooth!");
#endif
// adc setup
  // ADCを起動（ほかの部分で明示的にOFFにしてなければなくても大丈夫）
  adc_power_on();
  // ADC1_CH5を初期化
  adc_gpio_init(ADC_UNIT_1, ADC_CHANNEL_5);
  // ADC1の解像度を12bit（0~4095）に設定
  adc1_config_width(ADC_WIDTH_BIT_12);
  // ADC1の減衰を11dBに設定
  adc1_config_channel_atten(ADC1_CHANNEL_5, ADC_ATTEN_DB_11);
  // 電圧値に変換するための情報をaddCharに格納
  esp_adc_cal_characterize(ADC_UNIT_1, ADC_ATTEN_DB_11, ADC_WIDTH_BIT_12, 1100, &adcChar);

}

//=========================================================
//  auto_driving
//=========================================================
void auto_driving()
{
  int dDistance      = 0;
  int minDistance    = 0;

  //=========================================================
  //  calc distance to wall & current speed
  //=========================================================
  dDistance = preDistance - s1;
  curSpeed = (dDistance * 108) / (int)dTime;
  //=========================================================
  //  detect near to wall and set reverse mode
  //=========================================================
  if ((s1 < MIN_DISTANCE_F) && (abs(dDistance) <= 5)) {
    stopCounter++;
    if (stopCounter > MAX_STOP_TIME && reverseMode == 0) {
      reverseMode = 1;
      stopCounter = 0;
    }
  } else {
    stopCounter = 0;
  }
  //=========================================================
  //  set reverse distance (expand 100ms)
  //=========================================================
  if (reverseMode == 1) {
    minDistance = MIN_DISTANCE_F + REVERSE_DISTANCE;
  } else {
    minDistance = MIN_DISTANCE_F;
  }
  //=========================================================
  //  calc distance and speed
  //=========================================================
  if(s1 < minDistance){                    // x < 100
    if (reverseMode == 0) {
      curDriveDir   = BRAKE;
      requestTorque = MAX_TORQUE;
    } else {
      curDriveDir = REVERSE;
//      requestTorque = map(s1, STP_DISTANCE_F, MIN_DISTANCE_F, MIN_POWER + dAngle / 2, maxSpeed * LOW_SPEED);
//      requestTorque = MIN_POWER + dAngle / 2; 
      requestTorque = MIN_POWER; 
    }
  } else {
    reverseMode = 0;
    if (s1 > OVR_DISTANCE_F) {                // 500 < x
      curDriveDir = FORWARD;
      requestTorque = maxSpeed * MAX_SPEED;   // full throttle
    } else {                                  // 100 < x < 500
      curDriveDir = FORWARD;
      targetSpeed   = map(s1, MIN_DISTANCE_F, OVR_DISTANCE_F, 0, maxSpeed * MAX_SPEED);
      requestTorque = map(s1, MIN_DISTANCE_F, OVR_DISTANCE_F, MIN_POWER + dAngle / 10, maxSpeed * MAX_SPEED);
//      requestTorque = map(s1, MIN_DISTANCE_F, OVR_DISTANCE_F, MIN_POWER + dAngle / 2, maxSpeed * MAX_SPEED);
      if (targetSpeed <= curSpeed) {           // over speed
          curDriveDir   = BRAKE;
          requestTorque = MAX_TORQUE;
      }
    }
  }
  if (autoPilot == 2) {
    requestTorque = maxSpeed;
    curDriveDir = FORWARD;
  } 
  RC_drive(curDriveDir, requestTorque);
  //=========================================================
  //  calc forward time
  //=========================================================
  if (lastDriveDir != FORWARD && curDriveDir == FORWARD) {  // change to FORWARD
    sFwdTime = millis();
    eFwdTime = 0;                                           // clear elapse time
  }
  if (lastDriveDir == FORWARD && curDriveDir == FORWARD) {  // continue FORWARD
    eFwdTime = millis() - sFwdTime;                         // add elapse  time
    if (eFwdTime > 10000) {
      eFwdTime = 10000;
    }
  }
  preDistance  = s1;
  preSpeed     = curSpeed;
}

//=========================================================
//  auto_steering
//=========================================================
void auto_steering()
{
  int steerMax;                     // limit steering angle
  int dMin = MIN_DISTANCE_W;        // min distance to wall
  int dMax = MAX_DISTANCE_W;        // max distance to wall
  int pos;                          // position between wall to wall
  int oioOffset;                    // out in out offset
  int targetPos;                    // target position
  int targetPos2;                   // oio target
  int curPos;                       // current position

  //=========================================================
  //  detect straight
  //=========================================================
  if (s1 > OVR_DISTANCE_F &&  // detect straight
      s0 > MID_DISTANCE_W &&  // not near left wall
      s2 > MID_DISTANCE_W) {  // not near write wall
    steerMax = LIMIT_ANGLE ;  // limit steering
  } else {
    steerMax = MAX_ANGLE;
  }
  //=========================================================
  //  Limit wall distance
  //=========================================================
  if      (s0 > dMax) s0 = dMax;    // correct Max Value
  else if (s0 < dMin) s0 = dMin;    // correct Min Value
  if      (s2 > dMax) s2 = dMax;    // correct Max Value
  else if (s2 < dMin) s2 = dMin;    // correct Min Value
  //=========================================================
  //  detect out in out mode & calc targetPos
  //=========================================================
  if (dMode > 0) {                  // oio mode on
    if (courseLayout == LEFT) {
      oioOffset = OIO_OFFSET * dMode;     // keep near left wall
    } else if (courseLayout == RIGHT) {
      oioOffset = - OIO_OFFSET * dMode;   // keep near right wall
    } else {
      oioOffset = 0;
    }
    if (cornerFlag == 1 && s1 > OVR_DISTANCE_F) {      // straight : keep near outside wall
      oioOffset = - oioOffset;
      cornerFlag = 0;
      oioCount = 0;
    } else if (cornerFlag == 0 && s1 <= OVR_DISTANCE_F) {
      cornerFlag = 1;
      oioCount = 0;
    }
    oioCount ++;
  } else {
    oioOffset = 0;
  }
  targetPos = (s0 + s2) / 2;
  targetPos2 = constrain((s0 + s2) / 2 + oioOffset, MIN_DISTANCE_W, s0 + s2 - MIN_DISTANCE_W);
  if (targetPos - targetPos2 > 10) {
    targetPos = constrain(targetPos - oioCount * 2, targetPos2, targetPos);
  } else if (targetPos - targetPos2 < 10) {
    targetPos = constrain(targetPos + oioCount * 2, targetPos, targetPos2) ;
  }
/*
  Serial.print("\tSensor0:");
  Serial.print(rawS0);
//  Serial.print("\tStatus:");
//  Serial.print(st0);
  Serial.print("\tSensor1:");
  Serial.print(rawS1);
//  Serial.print("\tStatus:");
//  Serial.print(st1);
  Serial.print("\tSensor2:");
  Serial.print(rawS2);
//  Serial.print("\tStatus:");
//  Serial.print(st2);
  Serial.print("\tcourseLayout:");
  Serial.print(courseLayout);
  Serial.print("\tTargetPos:");
  Serial.print(targetPos);
  Serial.print("\tTargetPos2:");
  Serial.print(targetPos2);
  Serial.print("\toioCount:");
  Serial.print(oioCount);
  Serial.println();
*/
  //=========================================================
  //  calc steering angle
  //=========================================================
  curPos = s2;                      // standard wall is Right
  p = (targetPos - curPos) * kp;    // P control
  d = (p - prep) * 1000 / dTime * kd;  // calc differential
//  if (dMode == 1) {
//    d = (d + d1 + d2) / 3;
//    d2 = d1;
//    d1 = d;
//  }
  dAngle = constrain(p + d , -steerMax, steerMax);  // normalize dAngle -100 to 100
  prep = p;

  if (dAngle > 0) {
    steerDir = LEFT;
    dAngle = abs(dAngle);
  } else if (dAngle < 0) {
    steerDir = RIGHT;
    dAngle = abs(dAngle);
  } else {
    steerDir = CENTER;
    dAngle = 0;
  }
  //=========================================================
  //  kerikaeshi
  //=========================================================
  if (reverseMode == 1) {
    dAngle = KIRIKAESHI_ANGLE;          // kirikaeshi
    if (steerDir == RIGHT) {
      steerDir = LEFT;                  // counter steer
    } else  {
      steerDir = RIGHT;                 // counter steer
    }
  }
  //=========================================================
  //  steering control
  //=========================================================
  RC_steer(steerDir, dAngle);           // steering
  //=========================================================
  //  calc corner time
  //=========================================================
  if (lastSteerDir != steerDir || lastDriveDir != curDriveDir) { // change drive direction
    sCornerTime = millis();
    eCornerTime = 0;                            // clear elapse time
  }
  if (lastSteerDir == steerDir && lastDriveDir == curDriveDir) { // continue
    eCornerTime = millis() - sCornerTime;       // calc elapse time
    if (eCornerTime > 10000) {
      eCornerTime = 10000;
    }
  }
  //=========================================================
  //  detect course layout
  //=========================================================
  steerCount[steerDir]++;
  if (steerCount[LEFT] > 500 || steerCount[RIGHT] > 500) {
    if (steerCount[LEFT] > (steerCount[RIGHT] * 2)) { //grater than 2 times
      courseLayout = LEFT;
    } else if ((steerCount[LEFT] * 2) < steerCount[RIGHT] )
      courseLayout = RIGHT;
    } else {
      courseLayout = CENTER;                    // unknown
  }
  //=========================================================
  //  save old direction
  //=========================================================
  lastDriveDir = curDriveDir;                 // save last value
  lastSteerDir = steerDir;
}

//=========================================================
//  auto_pilot
//=========================================================
void auto_pilot()
{
  unsigned long t;                  // current time
  char buf[256];                    // serial pirnt buffer

  t = millis();                     // get current time
  dTime = t - preTime;                 // diff time
  preTime = t;
  auto_driving();
  auto_steering();
  //=========================================================
  //  Logging
  //=========================================================
#ifdef BT_ON
//  sprintf(buf, "\t%8d\t%4d\t%4d\t%4d\t%4d\t%4d\t%4d\t%5.2f\t%5.2f\t%1d\t%3d\t%5.3f\t%5.3f\t%3d\t%3d\t%1d\t%1d\t%1d",
//                t, rawS0, st0, rawS1, st1, rawS2, st2, p, d, steerDir, dAngle, kp, kd, requestTorque, curSpeed, curDriveDir, courseLayout, dMode);
//  sprintf(buf, "\t%8d\t%4d\t%4d\t%4d\t%5.2f\t%5.2f\t%1d\t%3d\t%5.3f\t%5.3f\t%3d\t%3d\t%1d\t%1d\t%1d",
//                t, rawS0, rawS1, rawS2, p, d, steerDir, dAngle, kp, kd, requestTorque, curSpeed, curDriveDir, courseLayout, dMode);
  sprintf(buf, "\t%8d\t%4d\t%4d\t%4d\t%5.2f\t%5.2f\t%1d\t%3d\t%5.3f\t%5.3f\t%3d\t%3d\t%1d\t%1d\t%1d\t%04d",
                t, rawS0, rawS1, rawS2, p, d, steerDir, dAngle, kp, kd, requestTorque, curSpeed, curDriveDir, courseLayout, dMode, voltage);
    SerialBT.println(buf);
#endif
//  SerialBT.println(buf);
}
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
void loop()
{
  uint32_t aVoltage   = 0;           // Battery ave voltage

  //=========================================================
  //  get VL53L0X TOF sensor value
  //    S0: left S1: center S2: right
  //=========================================================
#ifdef SENSOR_VL53L1X
  rawS0 = sensor0.read();        // read left  sensor
  rawS1 = sensor1.read();        // read front sensor
  rawS2 = sensor2.read();        // read right sensor
  // detect overrange error and collect

  st0 = sensor0.ranging_data.range_status;
  st1 = sensor1.ranging_data.range_status;
  st2 = sensor2.ranging_data.range_status;

   if (st0 != 4)  ps0 = s0 = rawS0;                  // if range error occred set previus value
   else           s0 = ps0;
   if (st1 != 4)  ps1 = s1 = rawS1;
   else           s1 = ps1;
   if (st2 != 4)  ps2 = s2 = rawS2;
   else           s2 = ps2;  

#else
  s0 = rawS0 = sensor0.readRangeContinuousMillimeters();
  if (sensor0.timeoutOccurred()) maxSpeed = 0;        // sonsor0 error ! emergency stop
  s0 = constrain(s0 - BODY_CLEARANCE_W, 0,  MAX_DISTANCE_W);
  s1 = rawS1 = sensor1.readRangeContinuousMillimeters();
  if (sensor1.timeoutOccurred()) maxSpeed = 0;        // sensor1 error ! emergency stop
  s1 = s1 - BODY_CLEARANCE_F;
  s2 = rawS2 = sensor2.readRangeContinuousMillimeters();
  if (sensor1.timeoutOccurred()) maxSpeed = 0;        // sensor2 error ! emergency stop
  s2 = constrain(s2 - BODY_CLEARANCE_W, 0,  MAX_DISTANCE_W);
  //s0 = sensor0.readRangeSingleMillimeters();
  //s1 = sensor1.readRangeSingleMillimeters();
  //s2 = sensor2.readRangeSingleMillimeters();
#endif
//=========================================================
//  Bluetooth Serial Control
//=========================================================
  if(SerialBT.available()){
    char action = SerialBT.read();
    if (action == 'a' ){
      if (autoPilot == 0) {
        autoPilot = 1;
        maxSpeed = MAX_POWER;
#ifdef BT_ON
        SerialBT.println("\tTime\tS0\tS1\tS2\tD\tP\tDIR\tAngle\tKp\tKd\trequestTorque\tcurSpeed\tcurDriveDir\tLayout\tdMode/tBattery");
//        SerialBT.println("\tTime\tS0\tst0\tS1\tst1\tS2\tst2\tD\tP\tDIR\tAngle\tKp\tKd\trequestTorque\tcurSpeed\tcurDriveDir\tLayout\tdMode");
//        SerialBT.println("\tTime\tS0\tS1\tS2\tD\tP\tDIR\tAngle\tKp\tKd\trequestSpeed\tcurSpeed\tcurDriveDIr\tLayout\tdMode");
#endif
      } else {
        autoPilot = 0;
        maxSpeed = MIN_POWER;
      }
    } else if (action == 'A') {
      autoPilot = 2;
      maxSpeed = 0;
    } else if (action == 'M') {
      dMode++;
      if (dMode > 4) dMode = 4;
    } else if (action == 'm') {
      dMode--;
      if (dMode < 0) dMode = 0;
    } else if (action == 'S') {
      maxSpeed += 10;
      if (maxSpeed >= 255) maxSpeed = 255;
    } else if (action == 's') {
      maxSpeed -= 10;
      if (maxSpeed <= 100) maxSpeed = 100;
    } else if (action == '.' || action == '>') {
      Joy_X += 20;
      if (Joy_X >= 100) Joy_X = 100;
    } else if (action == ',' || action == '<') {
      Joy_X -= 20;
      if (Joy_X <= -100) Joy_X = -100;
    } else if (action == 'P') {
      kp += 0.025;
    } else if (action == 'p') {
      kp -= 0.025;
      if (kp <= 0) kp = 0;
    } else if (action == 'D') {
      kd += 0.025;
    } else if (action == 'd') {
      kd -= 0.025;
      if (kd <= 0) kd = 0;
    } else if (action == 'Q' || action == 'q' || action == ' ') {
      autoPilot = 0;
      maxSpeed = 0;
    }
  }
//=========================================================
//  Battery Check
//=========================================================
  BatCheckCount++;
  if (BatCheckCount >= 20) {
    BatCheckCount = 0;
    esp_adc_cal_get_voltage(ADC_CHANNEL_5, &adcChar, &voltage);
    voltage = voltage / 0.252;        // default : 0.244
    aVoltage = (voltage + pVoltage) / 2;
    if (aVoltage < 6000 && voltage > 1000) {
      RC_halt();
      Serial.print("Battery Voltage = ");
      Serial.print(voltage);
      Serial.println(" System Halt !");
      while(true);                // system halt
    }
    pVoltage = voltage;
  }
//=========================================================
//   Start Driving!
//=========================================================
  if (autoPilot == 1 || autoPilot == 2) {
    auto_pilot();
  } else {
    manual_pilot();
  }
}

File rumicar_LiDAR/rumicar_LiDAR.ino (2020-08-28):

//=========================================================
//  rumicar_LiDAR.ino :  RumiCar application
//  History     : V1.0  2020-08-28 support LiDAR 
//=========================================================
#include "M5Atom.h"               // CPU: M5 Atom Matrix
#include "BluetoothSerial.h"

#define BT_ON
#ifdef BT_ON
BluetoothSerial SerialBT;
#endif
//=========================================================
//  RumiCar Default Parameter
//=========================================================
#define DEVICE_NAME     "RumiCar_LiDAR" // BLE Device Name

//=========================================================
//  auto pilot variables difinition
//=========================================================

//=========================================================
//  Arduino setup function
//=========================================================
void setup()
{
  M5.begin(true, false, true);
  delay(50);
  M5.dis.clear();
  Serial.begin(115200);
  Serial2.begin(115200, SERIAL_8N1, 32, 26);// Grove 32:RX 26:TX
#ifdef BT_ON
  Serial.println("Start bluetooth!");
  SerialBT.begin(DEVICE_NAME);
  Serial.println("The device started, now you can pair it with bluetooth!");
#endif
}

//=========================================================
//  Arduino Main function
//=========================================================
void loop()
{
  char action;
  M5.update();

  if (Serial2.available()) {
    // Serial2(Grove) to Serial(PC)
    int inByte = Serial2.read();
    SerialBT.write(inByte);
  }
}

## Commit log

2020-08-18 support esp32mini
2020-08-19 ESP32mini schematic
2020-08-19 debug servo mode
2020-08-23 debug sensor
2020-12-02 steer ok
2020-12-05 debug brake
2020-12-06 add pre torque
2020-12-12 change pid param
2020-12-12 power control
2020-12-13 Add Battery Check
2020-12-15 voltage check
